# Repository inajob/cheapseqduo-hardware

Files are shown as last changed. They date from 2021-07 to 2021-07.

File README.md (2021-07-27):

# これはなに？

勢いで作った基板です。

CheapSeqDuo

- Arduino Nanoを2つ搭載し
- ピアノ風のキーボード
- OLED(128x64または128x32）
- 単4電池x4本
- オーディオジャック
- ボリューム
- 10cm x 10cm

1つのArduinoをコントローラに、もう一つのArduinoを音源用に、と思い配置しています。

# TODO

- ファームウェアがまだない（一応自分の作った物を近いうちに公開しますが、大したものではないのでそれぞれ作るのが良いと思います）
- BOMがない

# 既知のバグ

- 2つのArduinoのTX,RXが直結されているので、2つ基板に配置するとArduinoとして書き込みできない（致命的）
  - パターンカットしてスイッチでTX,RXを繋げるようにするのがよさそう
- D13にLEDがついている関係でキースキャンがうまくできない、プルアップ抵抗を入れる事で回避できる
- (仕様) オーディオジャック、ボリュームのフットプリントはあるが未接続です。自分で手配線してArduinoと接続したり、オーディオアンプを構成したりしてください。

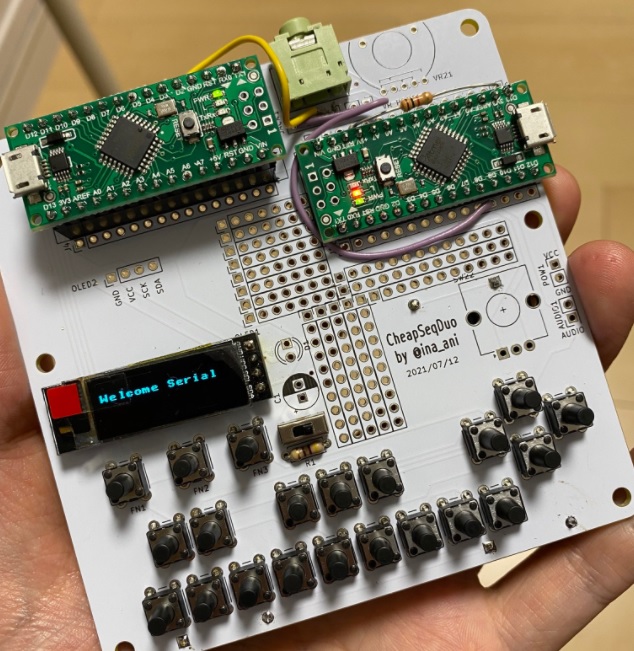
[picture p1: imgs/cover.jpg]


# 感謝

この基板はALLPCBのキャンペーンで無料で基板が作れるという事で作り始めたものです。

下記リンクからALLPCBを初めて利用すると、$30のクーポンがもらえますのでどうぞ。

[クーポン付きALLPCB入会URL](https://www.allpcb.com/?Mb_InviteId=77225)

(2021年7月現在 ALLPCBは「毎月送料含め基板無料キャンペーン」をやっているようで、この基板であれば5枚が無料で作れます。

# ライセンス

CC SA-BY とします。

（面白いボードができたら http://twitter.com/ina_ani まで教えてください。余ったら1枚ください！動くものが出来た場合はどこかで遊ばせてほしいです！）

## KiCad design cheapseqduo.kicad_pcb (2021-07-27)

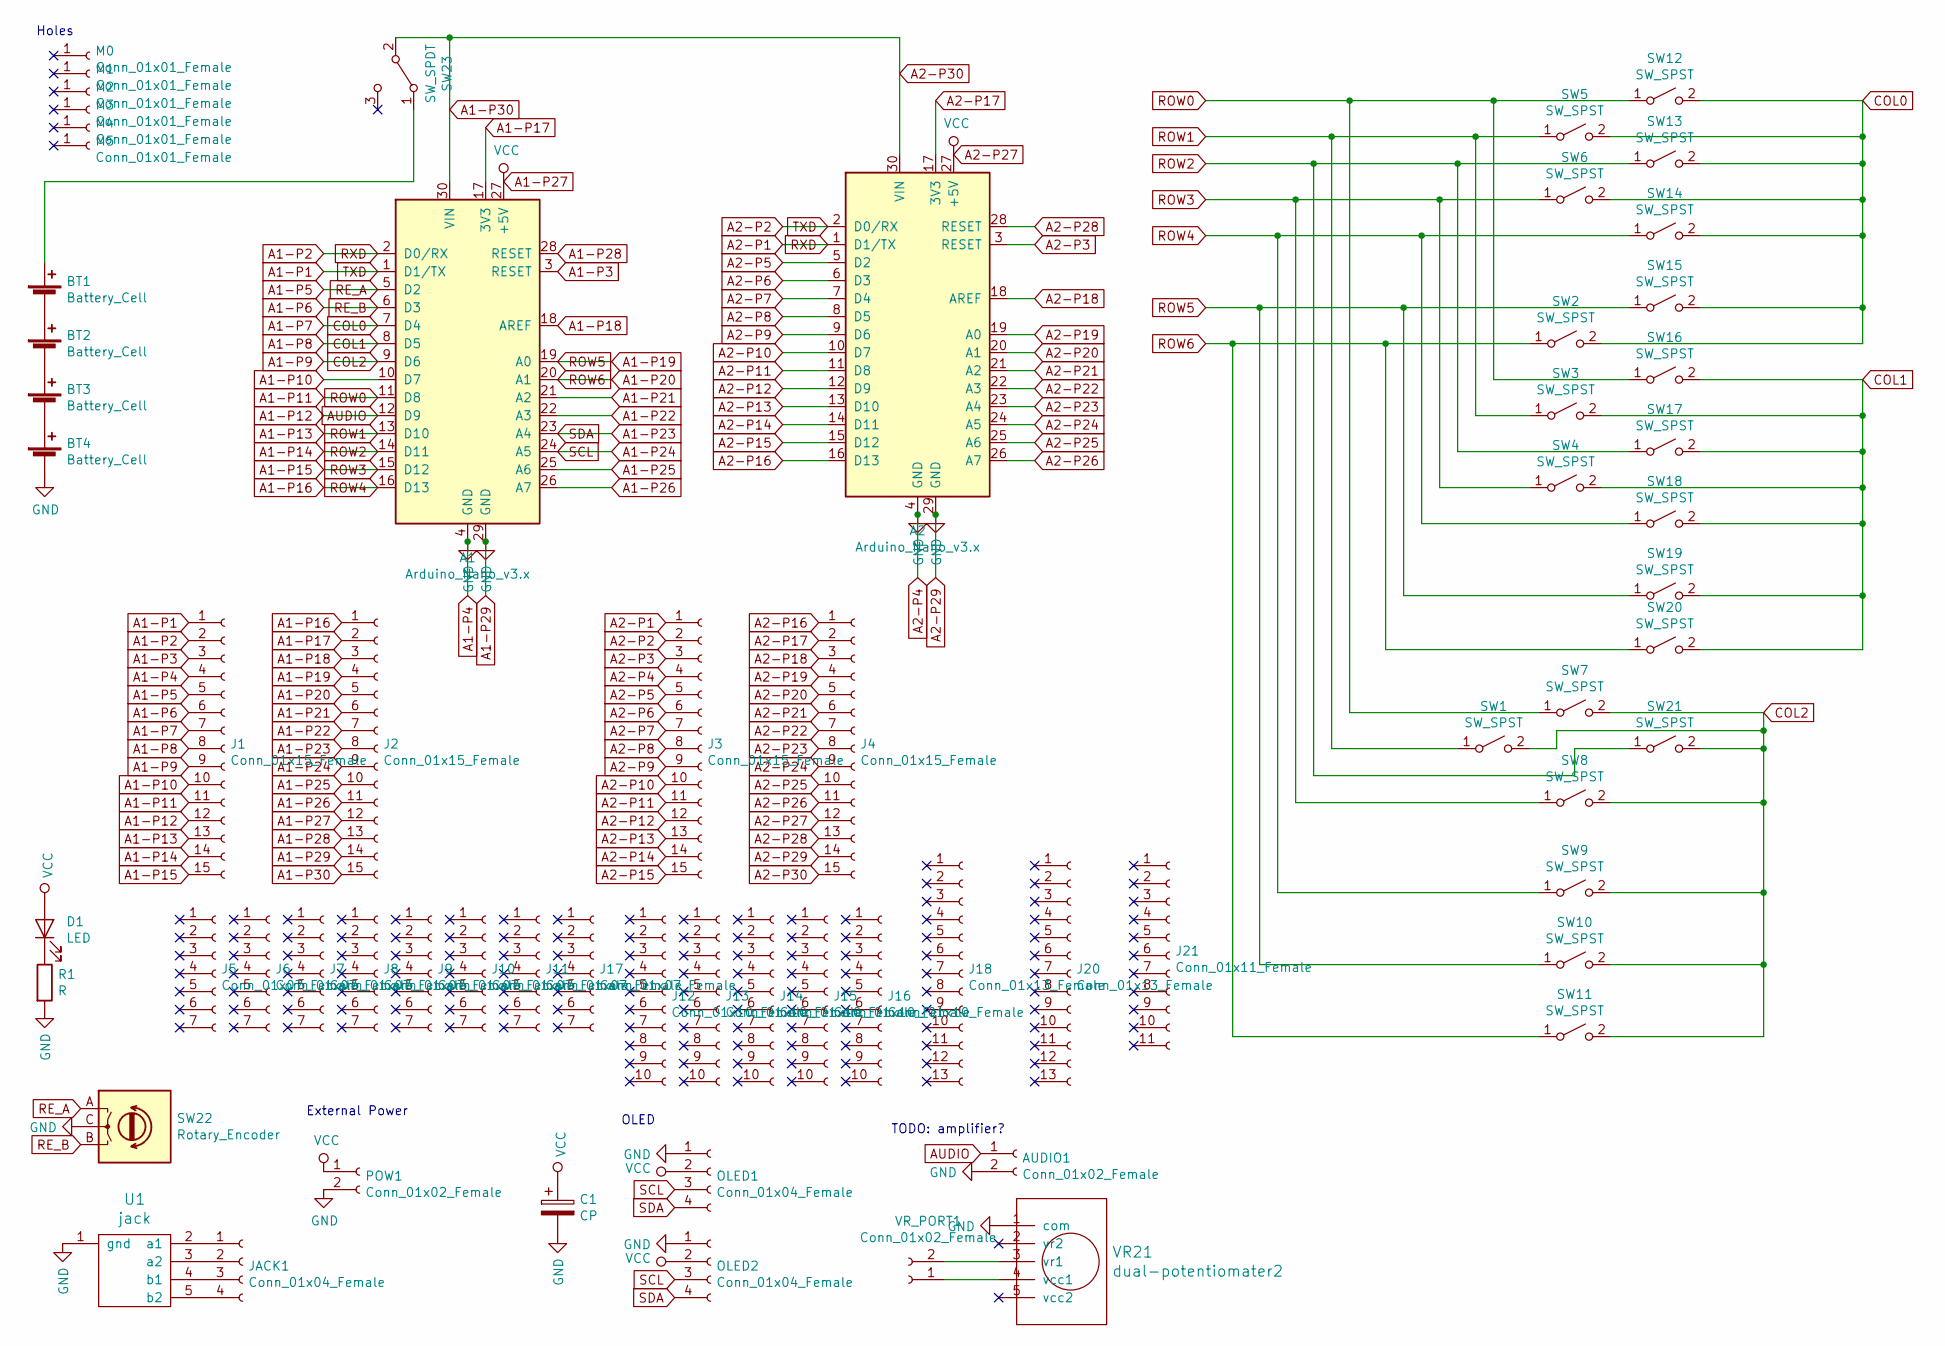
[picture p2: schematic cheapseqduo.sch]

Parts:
A1, A2: Arduino_Nano_v3.x; Arduino_Nano
AUDIO1: Conn_01x02_Female; PinHeader_2x01_P2.54mm_Vertical
BT1, BT2, BT3, BT4: Battery_Cell; BatteryHolder_Keystone_2466_1xAAA
C1: CP; CP_Radial_D6.3mm_P2.50mm
D1: LED; LED_D4.0mm
J1, J2, J3, J4: Conn_01x15_Female; PinHeader_1x15_P2.54mm_Vertical
J5, J6, J7, J8, J9, J10, J11, J17: Conn_01x07_Female; PinHeader_1x07_P2.54mm_Vertical
J12, J13, J14, J15, J16: Conn_01x10_Female; PinHeader_1x10_P2.54mm_Vertical
J18, J20: Conn_01x13_Female; PinHeader_1x13_P2.54mm_Vertical
J21: Conn_01x11_Female; PinHeader_1x11_P2.54mm_Vertical
JACK1: Conn_01x04_Female; PinHeader_1x04_P2.54mm_Vertical
M0, M1, M2, M3, M4, M5: Conn_01x01_Female; MountingHole_3.2mm_M3
OLED1, OLED2: Conn_01x04_Female; PinHeader_1x04_P2.54mm_Vertical
POW1: Conn_01x02_Female; PinHeader_1x02_P2.54mm_Vertical
R1: R; R_Axial_DIN0207_L6.3mm_D2.5mm_P7.62mm_Horizontal
SW1, SW2, SW3, SW4, SW5, SW6, SW7, SW8, SW9, SW10, SW11, SW12, SW13, SW14, SW15, SW16, SW17, SW18, SW19, SW20, SW21: SW_SPST; SW_PUSH_6mm_H8mm
SW22: Rotary_Encoder; RotaryEncoder_Alps_EC12E_Vertical_H20mm_CircularMountingHol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
SW23: SW_SPDT; PinHeader_1x03_P2.54mm_Vertical
U1: jack
VR21: dual-potentiomater2; potentiometer2
VR_PORT1: Conn_01x02_Female; PinHeader_1x02_P2.54mm_Vertical

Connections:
A1-P1: A1.1 (D1/TX), A2.2 (D0/RX), J1.1, J3.2
A1-P2: A1.2 (D0/RX), A2.1 (D1/TX), J1.2, J3.1
A1-P3: A1.3 (RESET), J1.3
A1-P5: A1.5 (D2), J1.5, SW22.A
A1-P6: A1.6 (D3), J1.6, SW22.B
A1-P7: A1.7 (D4), J1.7, SW2.2 (B), SW5.2 (B), SW6.2 (B), SW12.2 (B), SW13.2 (B), SW14.2 (B), SW15.2 (B)
A1-P8: A1.8 (D5), J1.8, SW3.2 (B), SW4.2 (B), SW16.2 (B), SW17.2 (B), SW18.2 (B), SW19.2 (B), SW20.2 (B)
A1-P9: A1.9 (D6), J1.9, SW1.2 (B), SW7.2 (B), SW8.2 (B), SW9.2 (B), SW10.2 (B), SW11.2 (B), SW21.2 (B)
A1-P10: A1.10 (D7), J1.10
A1-P11: A1.11 (D8), J1.11, SW7.1 (A), SW12.1 (A), SW16.1 (A)
A1-P12: A1.12 (D9), AUDIO1.1, J1.12
A1-P13: A1.13 (D10), J1.13, SW1.1 (A), SW3.1 (A), SW5.1 (A)
A1-P14: A1.14 (D11), J1.14, SW13.1 (A), SW17.1 (A), SW21.1 (A)
A1-P15: A1.15 (D12), J1.15, SW4.1 (A), SW6.1 (A), SW8.1 (A)
A1-P16: A1.16 (D13), J2.1, SW9.1 (A), SW14.1 (A), SW18.1 (A)
A1-P17: A1.17 (3V3), J2.2
A1-P18: A1.18 (AREF), J2.3
A1-P19: A1.19 (A0), J2.4, SW10.1 (A), SW15.1 (A), SW19.1 (A)
A1-P20: A1.20 (A1), J2.5, SW2.1 (A), SW11.1 (A), SW20.1 (A)
A1-P21: A1.21 (A2), J2.6
A1-P22: A1.22 (A3), J2.7
A1-P23: A1.23 (A4), J2.8, OLED1.4, OLED2.4
A1-P24: A1.24 (A5), J2.9, OLED1.3, OLED2.3
A1-P25: A1.25 (A6), J2.10
A1-P26: A1.26 (A7), J2.11
A1-P27: A1.27 (+5V), A2.27 (+5V), C1.1, D1.2 (A), J2.12, J4.12, OLED1.2, OLED2.2, POW1.1
A1-P28: A1.28 (RESET), J2.13
A1-P29: A1.4 (GND), A1.29 (GND), A2.4 (GND), A2.29 (GND), AUDIO1.2, BT4.2 (-), C1.2, J1.4, J2.14, J3.4, J4.14, OLED1.1, OLED2.1, POW1.2, R1.2, SW22.C, U1.1 (gnd), VR21.1 (com)
A1-P30: A1.30 (VIN), A2.30 (VIN), J2.15, J4.15, SW23.2 (B)
A2-P3: A2.3 (RESET), J3.3
A2-P5: A2.5 (D2), J3.5
A2-P6: A2.6 (D3), J3.6
A2-P7: A2.7 (D4), J3.7
A2-P8: A2.8 (D5), J3.8
A2-P9: A2.9 (D6), J3.9
A2-P10: A2.10 (D7), J3.10
A2-P11: A2.11 (D8), J3.11
A2-P12: A2.12 (D9), J3.12
A2-P13: A2.13 (D10), J3.13
A2-P14: A2.14 (D11), J3.14
A2-P15: A2.15 (D12), J3.15
A2-P16: A2.16 (D13), J4.1
A2-P17: A2.17 (3V3), J4.2
A2-P18: A2.18 (AREF), J4.3
A2-P19: A2.19 (A0), J4.4
A2-P20: A2.20 (A1), J4.5
A2-P21: A2.21 (A2), J4.6
A2-P22: A2.22 (A3), J4.7
A2-P23: A2.23 (A4), J4.8
A2-P24: A2.24 (A5), J4.9
A2-P25: A2.25 (A6), J4.10
A2-P26: A2.26 (A7), J4.11
A2-P28: A2.28 (RESET), J4.13
unnamed: BT1.1 (+), SW23.1 (A)
unnamed: BT1.2 (-), BT2.1 (+)
unnamed: BT2.2 (-), BT3.1 (+)
unnamed: BT3.2 (-), BT4.1 (+)
unnamed: D1.1 (K), R1.1
unnamed: JACK1.1, U1.2 (a1)
unnamed: JACK1.2, U1.3 (a2)
unnamed: JACK1.3, U1.4 (b1)
unnamed: JACK1.4, U1.5 (b2)
unnamed: VR21.3 (vr1), VR_PORT1.2
unnamed: VR21.4 (vcc1), VR_PORT1.1

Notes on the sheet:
TODO: amplifier?
OLED
External Power
Holes

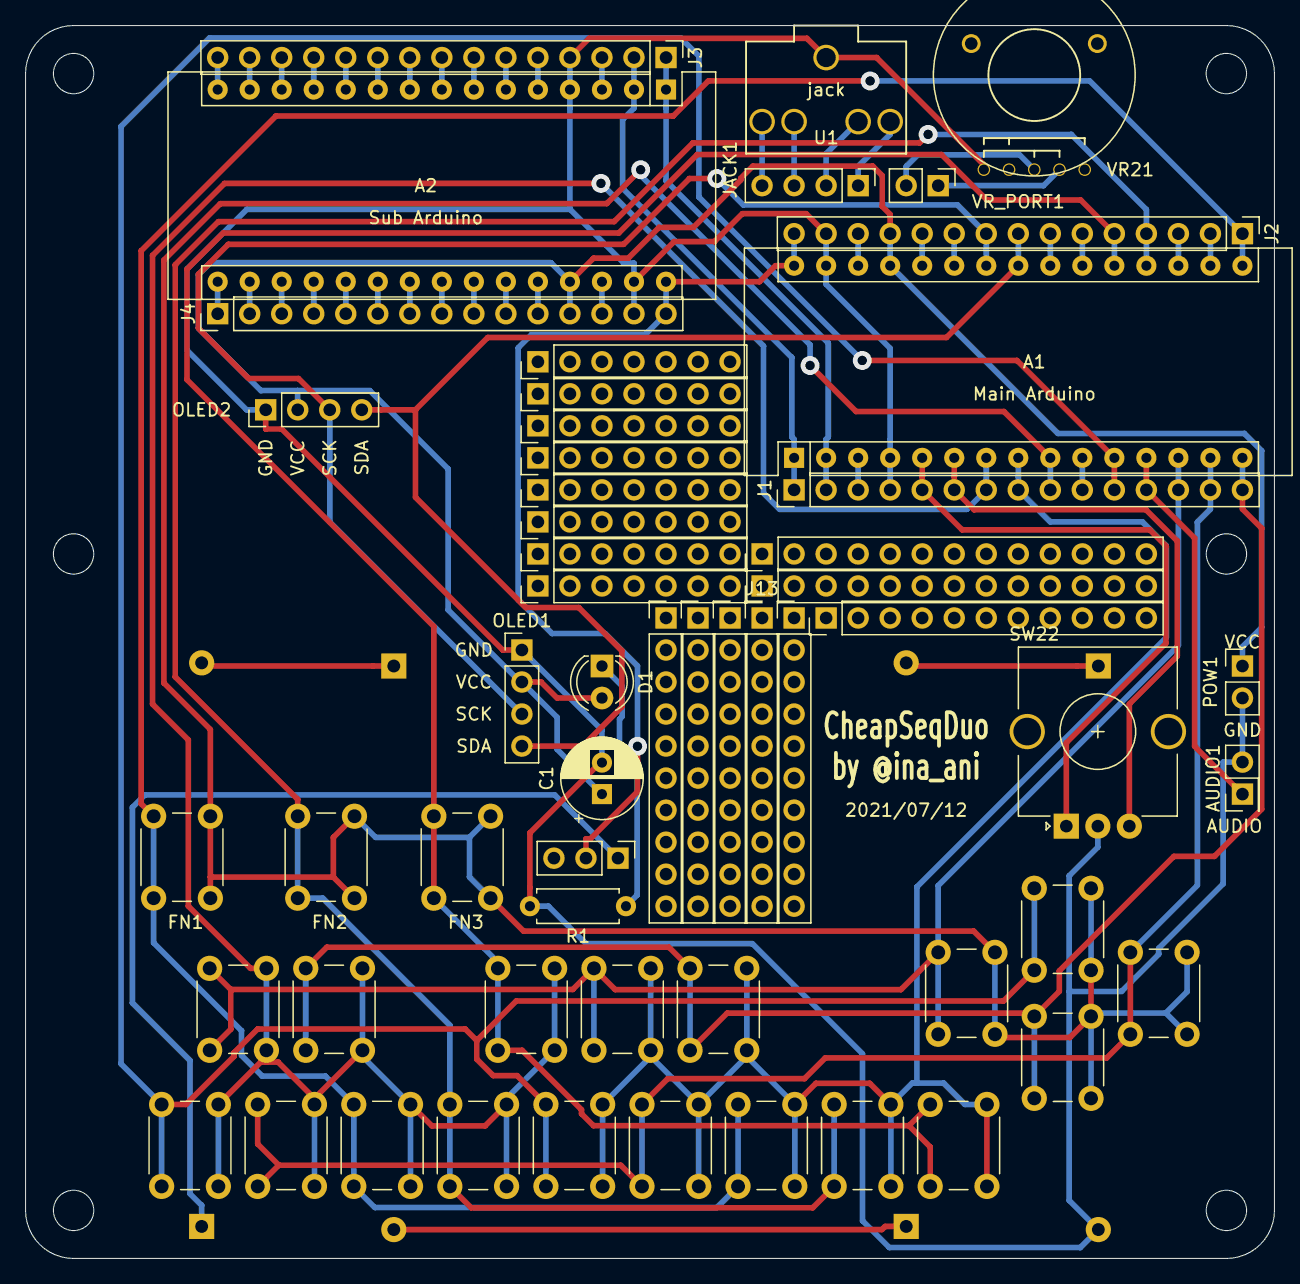
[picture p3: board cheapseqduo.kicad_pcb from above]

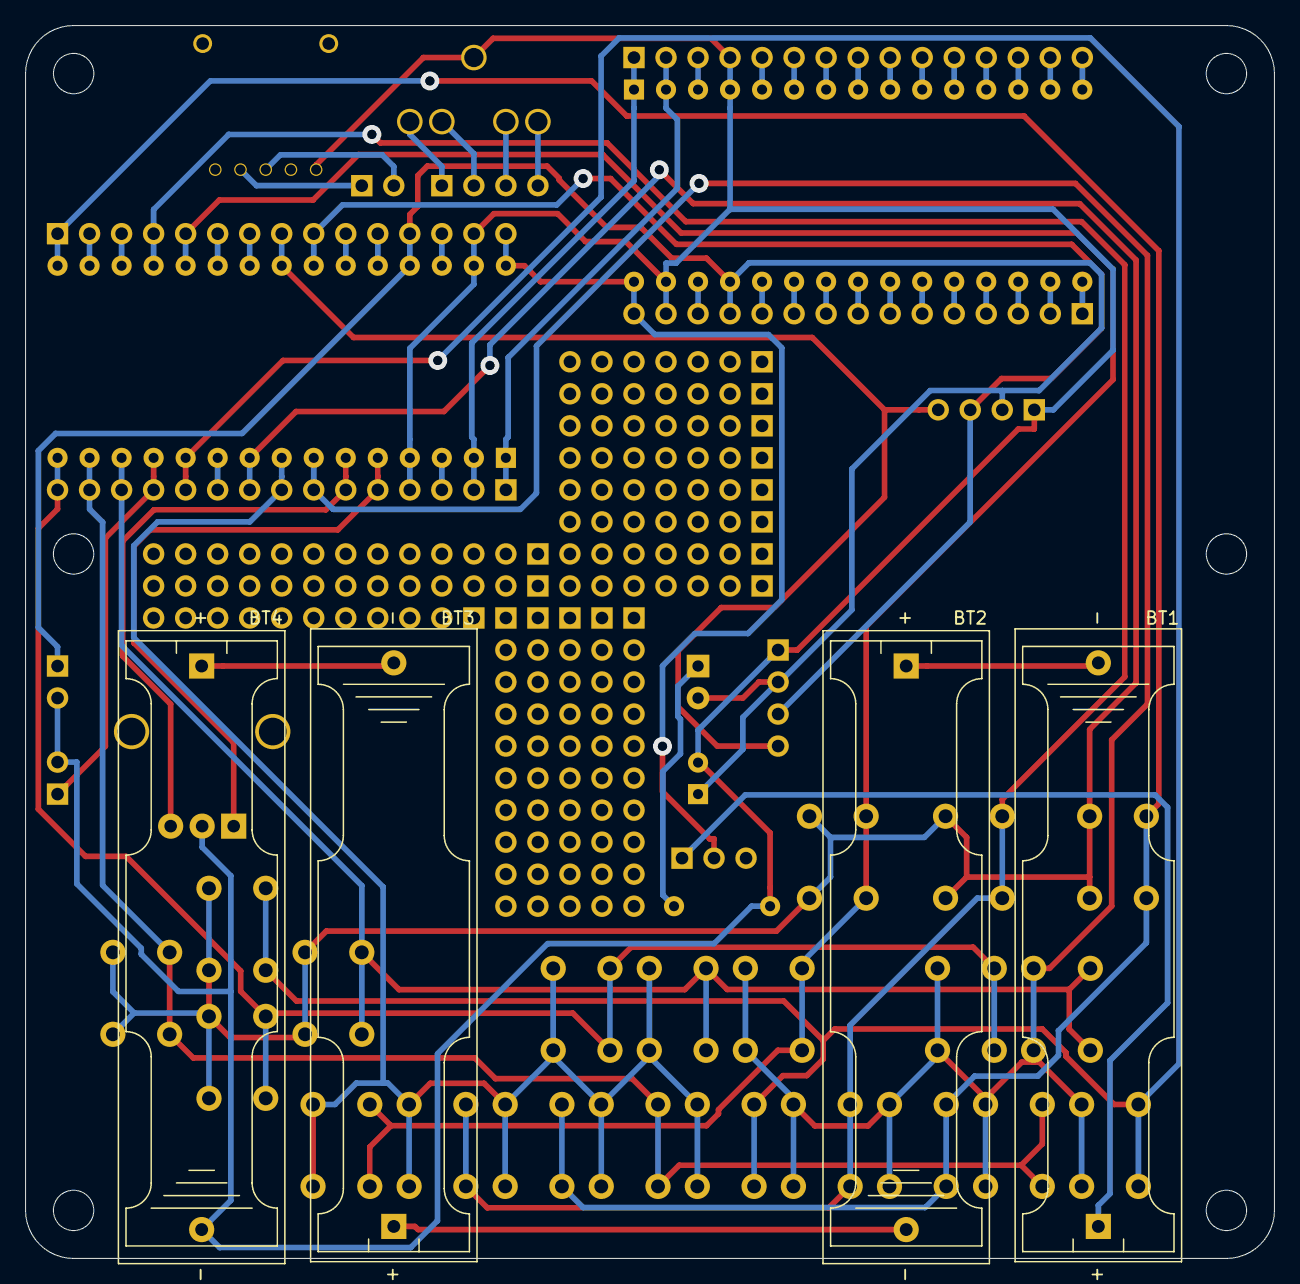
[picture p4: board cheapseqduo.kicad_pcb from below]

Board: 2 copper layers, 99.1 x 97.8 mm, 66 parts (4 on the bottom side), 64 nets.
